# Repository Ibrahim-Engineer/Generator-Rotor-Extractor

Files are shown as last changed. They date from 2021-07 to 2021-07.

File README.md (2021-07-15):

# Generator-Rotor-Extractor

This was a project I was doing for Mechnaic Systems Design, in which we were to implement all the mechanical engineering skills and knowledge we had at our disposal to design a proposal to accomplish something in industry. The following file finaldraft.pdf is the report that should be read to understand the project, while the assembly is going to show the rotor extraction mechanism.

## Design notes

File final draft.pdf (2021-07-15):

## Generator Rotor Extractor

MENG 3309 MSD REPORT

030-Group11

REPORT SUBMITTED BY: Anishkumar Patel

Mohammed Waheed

David Rubio

Luis Rosario

Samuel Thompson

We certify that the narrative, diagrams, figures, tables, calculations and analysis in this report are our own work.

DATE REPORT DUE: | April 25, 2021
DATE REPORT SUBMITTED: | April 25, 2021

MECHANICAL ENGINEERING DEPARTMENT HOUSTON ENGINEERING CENTER COLLEGE OF ENGINEERING
THE UNIVERSITY OF TEXAS AT TYLER

Abstract

Turbine generators are machines that generate electricity by converting mechanical energy

to electrical energy. They are comprised of two main components, a rotor and a stator unit. The

rotor is covered in wires and is spun by mechanical energy inside a stator unit, which has wires

coiled inside, creating an electric magnet. Over time of operation the generator’s components wear

and have to be serviced at a minimum three times a year. This becomes a problem because in order

to access the components to service them the rotor must be extracted from the generator. In this

proposal the rotor model that is tasked to be extracted is from CMT Machines and weights in at

129000 pounds. This proposal is about designing a process in which the rotor will be extracted

using a guided rail system while being pulled by a winch. In order to achieve this, components

were designed to distribute the load of the rotor among two support structures which are further

divided into three components, a seat which supports the rotor, and two Hillman rollers which

support the seat. The next step was to design a guided rail system in which the rollers would

transition the rotor along a two channel rails, both placed on parallel to another. Next the device

that will pull the rotor and supports will be a hydraulic winch model AQ-JM2 by Winch Machines.

Finally, all these components will be held up by a Generator Field Support Platform made by MDA

Turbines. Upon analysis of the components when placing the load of the rotor, the seat was found

to have a safety factor of 15 with a displacement of 7.926E-5 inches. The rollers was then analyzed

where each of the rolls had a safety factor of 15 and a displacement 1.851E-5 inches. The final

analysis for this design was the winch which had a speed of 10.5 inches per second, torque 237741

lbf*in, and 54 Horse Power, when extracting the load of the rotor and its support along the rail

system The one component that can be modified however, in this proposal is the seat due to it

having such a high safety factor it is unnecessary to have a design where too much material is used

to achieve this outcome.

TABLE OF CONTENTS

Introduction

Generators

Turbine generators are devices that convert mechanical energy into electrical energy. The

way this is accomplished is by using an electromagnet, a magnet produced by electricity. The main

components of the generator that produce the electromagnet are the generator stator and the rotor.

The stator unit is a stationary unit with insulated wires coiled around an internal cylinder contained

within the unit. The rotor is comprised of wires coiled and placed on a shaft. The rotor turns within

the stator unit producing the electromagnetic power.

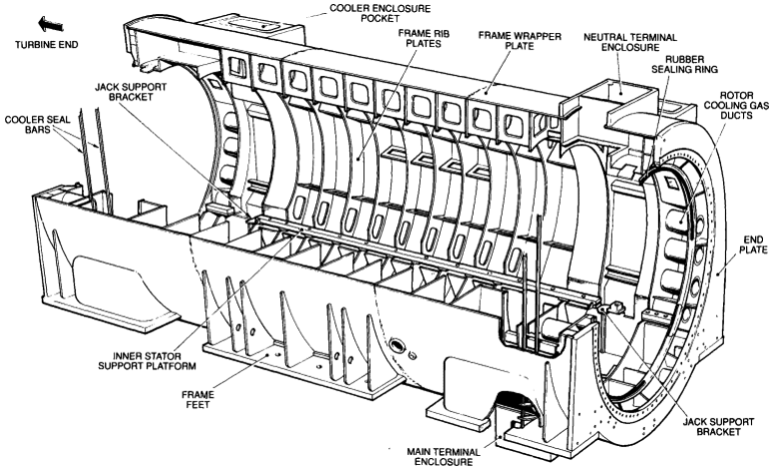
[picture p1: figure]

Fig 1. Depicts a diagram of a generator stator, which houses a rotor [1].

As shown in Fig 1. the stator is what houses the generator rotor, the rotor spins in the stator

and induces a current to produce energy.

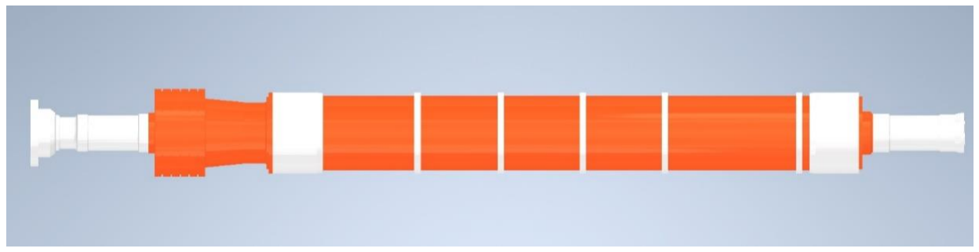
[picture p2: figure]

Fig 2. Generator rotor from City Machines Technology part number 98972-RGXLA [2].

As shown in Fig 2. a rotor shaft is selected and displayed above. This assembly is what

would be housed in the stator when fully operational.

Rotor Maintenance

Overtime the rotor will need some maintenance and may even need to be replaced after the

life cycle of the part comes to an end.

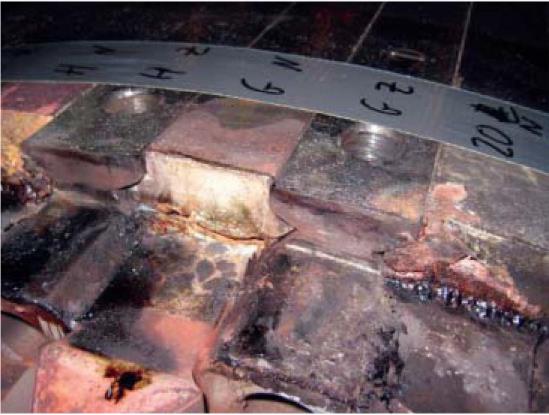
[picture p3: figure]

Fig 3. Image of rotor melted seat with melted insulated coiled wire taken from Figure 2

"Ageing Generator Rotor: Refurbishment or Removal from Service?" [5].

Some of the common damages that can occur to a generator rotor are the coiled wires that

can corroded from wear. As shown in Fig 3., a rotor can experience burns cracks along with its

components and even damage the stator unit inside when in operation. Due to the extensive

components that can wear in a turbine generator, rotors need to be serviced at least three times a year. In order to do this the rotor must be taken out of the stator unit for it to be serviced. This

process is known as generator rotor removal or extraction. Generator rotor extraction is done by a

multi-step process in which multiple mechanisms work in tandem for the rotor to be extracted. The

extraction is done by pulling the rotor from the generator’s stator horizontally while it is suspended

or held up from the bottom in pure translation. If the rotor is not removed in an extremely

controlled fashion, and becomes imbalanced, the rotor can damage the generator stator.

Proposed Method

The motivation of this proposal is to find a way to optimize the process for extracting a

rotor with a minimal cost, a verifiable factor of safety, and a projected life cycle. This can be

achieved by comparing another process for rotor extraction to generator rotor extraction. The

model for the assembly as shown in Fig 2. is what this proposal is challenged with removing from

the stator unit.

In order to remove a rotor from a stator unit a method of extracting has been determined to

be using a rail guided system. The rotor itself will be supported by structures that can support its

weight while being rolled upon a rail. The rotor then will be pulled by a winch using a cable. The

entire structure can then be supported by a platform which will be able to support the forces being

enacted on the structure during the whole process.

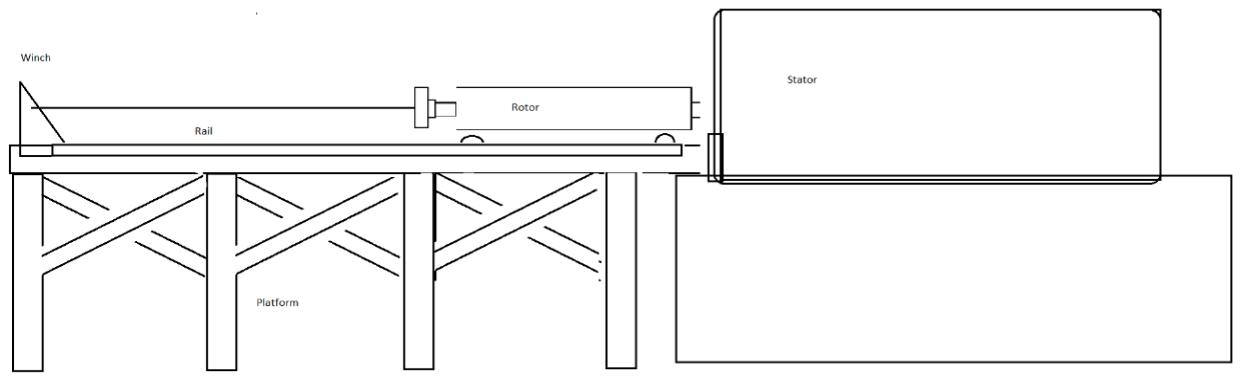
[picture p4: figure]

Fig. 3. Proposed Drawing.

Problem Statement

In designing the proposed design, the ideal process is putting together a detailed design

that will help accomplish the goal of extracting a generator rotor from a stator unit. The following

rotor as shown in Fig 2. from CMT is weighing in at approximately 129000 pounds, is what will

be intended to be extracted for this design. The process in designing an extraction method that is

proposed will present challenges. Such as when finding the distributed weight, the rollers will have

to take from the rotor. Another challenge will be finding a cable winch that can pull the rotor

including its supports. The guided railing system also will have to hold the weight of the rotor and

support system. This rail then has to be placed on a platform that will keep the guided rail in its

intended route, so it won’t be displaced from the shear forces enacting on it by the rotor and the

supports while it is being pulled by the winch.

Objectives

To minimize human error and unintentional damages to a rotor when being extracted; the

process must be optimized with a mechanism to extract the generator rotor. The rotor assembly

must be supported and guided as it is pulled at a safe rate for it to be extracted successfully.

In order to design the rotor extractor a similar method as shown in “Rotor Removal from Large

Machines”, a design of a rotor extractor can be made. The rotor extractor can be split into three

components a guided rail, support structures, and a winch. The guided rail is for the extraction to

occur with precision and not cause the rotor assembly to not damage itself or the stator. The support

structures are to distribute the load of the assembly and move along the guided rail. Finally, the

winch will use a cable that will pull the supports uniformly to ensure they move along the guided

rail. Building on this the goal is to extract the rotor from its stator unit for 55 feet.

Preliminary Literature

In “Rotor Removal from Large Machines”, the process in removing a rotor is shown to be

done by a mechanism that works by pulling a rotor out of its casing while resting on jacks guided

along a determined path [3]. It begins by first pulling the rotor out of the casing slightly till it rests

upon jacks that act as supports. The jacks are aligned to be positioned with the casing of the rotor

so the transition will be smooth. The jacks then will move along the guided tracks for the extraction

to be complete. This method helps show the type of supports that can be designed when moving

the rotor from the stator unit.

In "Predictive Control of Hydraulic Winch Motion Control" hydraulic winches are used to

pull large loads. However, it is stated due to the nonlinear way a load can be pulled when being

dragged by a winch a guided rail system is necessary for the load to be transported in a linear

fashion [4]. This will help with designing a guided rail which will keep the rotor and supports to

be aligned with the winch.

Methodology.

When designing each component, a backwards approach is being taken by first designing

supports which can hold the weight for the rotor and its dimensions. Next, a winch that can pull

the weight of the rotor and the supports can be selected. Finally, the guided rail system with a

platform can be then designed to hold the weight of the rotor, the supports, and a winch at the end.

Supports

The rotor that is most used has dimensions of half a meter in diameter while being 503

inches long and weights roughly 129000 pounds. Based on the dimensions stated a support to carry

this rotor can be designed. The load of the rotor can be distributed between two supports. This

means that the weight for each support will then be the total weight of the rotor and assembly divided by two giving the value 64500 pounds. The location of the supports will be placed along

the assembly for it equal distribution of weight. The supports will be comprising of two

components a seat in which the rotor rests on and two rollers where the seat can roll on.

When designing the seats, it is important to keep in mind where the seats will support the

assembly. The seats must hold an approximate diameter of the rotor has a value of 41 inches.

Another aspect of the seat will be to have two indentation on the bottom for the two rollers.

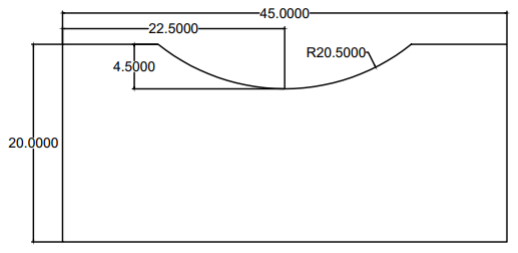
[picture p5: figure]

Fig 4. Shows the sketch of the seat.

As shown in Fig 4., the seat dimensions are made to hold about 41 inches in diameter in

rotor. The seat has been extruded to 18 inches and has slots on the bottom for the rollers. The total

mass for the support is 3332 pounds.

The next component that has to be chosen is the rollers, which will be located on either

side of the seat. The rollers are chosen from Hillman Rollers based on the weight that is being

distributed on each roller. Since the Since the seat adds weight to the distribution along with the

supported weight of the rotor assembly the total weight the rollers have to support is 67832 pounds.

This means each roller will have to support about 33916 pounds. or about 17 us tons. In order for

17 us tons to be supported the Hillman Rollers 20 Ton Capacity T Style Roller 20-T (HIL20-T) is

selected.

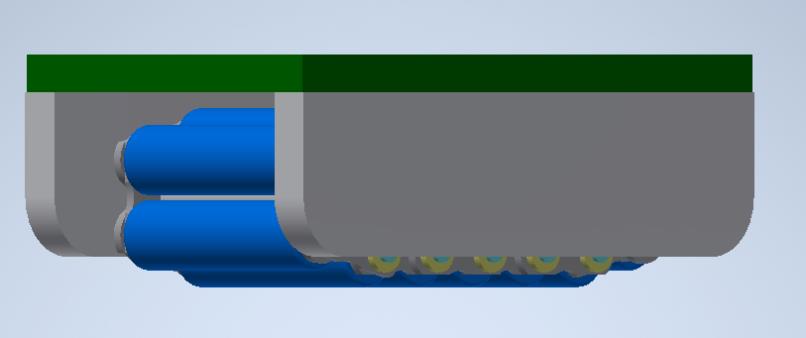
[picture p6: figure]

Fig 5. Shows the HIL20-T Roller which will attach to the seat.

Guided Rail System

After the Seat has been designed and the roller has been selected the next component for

design is the guided rail. The guided rail is for the rollers to roll upon so the rotor assembly will

be moved precisely and safely without being damaged or damaging the stator unit.

The first step is to design a rail with a length that will allow for the rotor to be completely

situated on it when the extraction is complete and for room so personal can service it. Since the

rotor is about 42 feet, a rail system that has the length of 60 feet is being designed. Another aspect

is the channel dimensions of the rail, in which the rollers will move in. According to the Hilman

official dimensions of HIL20-T Roller the width is about 6.5 inches and height is 3.75 inches. Due

to this width the channel width of the rail is 6.5 inches with inner height of the channel 2.5 inches.

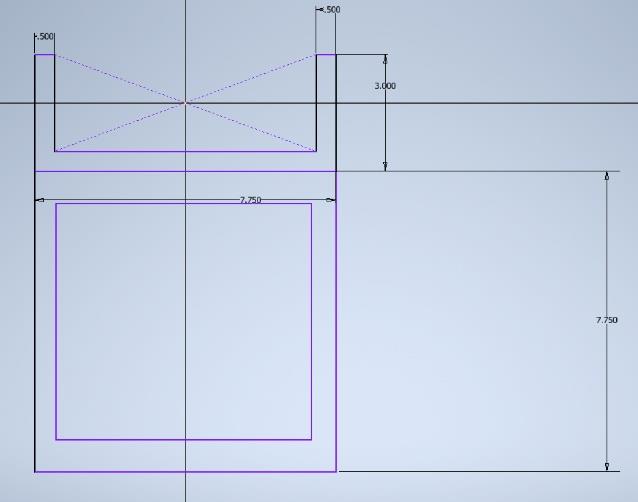
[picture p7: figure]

Fig 6. Shows the sketch of the guided rail component.

The guided rail as seen in Fig 6. has the length of 20 feet. Since the objective is to design

a rail system that will extend to about 60 feet, three components will be used end to end to achieve

the desired length. Also due to the distributed load of the rotor being divided on either side on

rollers, there will be two sets of rails systems put about 20 inches apart. When all put together the

60 feet rail will have 13 sleepers placed 55 inches apart underneath the rail with following

dimensions as shown below

Winch

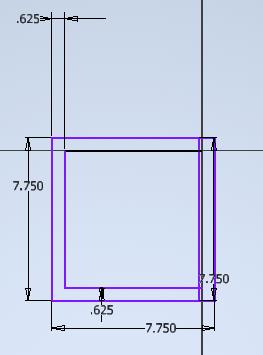
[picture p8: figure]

In order to determine the winch that will be used to extract the rotor the horizontal force

needed to pull the supports and the rotor itself on the guided rail system has to be first determined.

The first step is to find the combined weight of the rotor and supports. There are 4 rollers being

used in total each weighing at 47 pounds., giving a total weight of 188 pounds. There are two seats

being used in the design each weighing at 3355 pounds. giving a total weight of 6670 pounds. All

the support weight combined with the weight of the rotor, 129000 pounds., gives a value of 135870

pounds. Next using the friction coefficient for the steel being used on the rollers, .25, the determined force needed to pull the rotor with the supports come to a value of 33963 pounds or

about 17 U.S. tons.

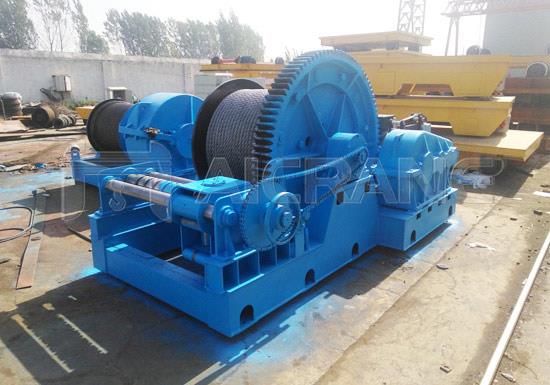
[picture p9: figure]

Fig 7. The AQ-JM2 series hydraulic pull winch.

As shown in Fig 7., the winch, AQ-JM2, has been selected with a pull strength of 20 tons.

Platform

The platform has the length of 65 feet to contain the guided rail system and the winch

which gives a total length of about 63 feet and a width of 5 feet. Based on the dimensions a truss

system along with vertical beams are used to support the structure. These vertical support beams

will be adjusted to level the platform to adhere to the height of the stator unit.

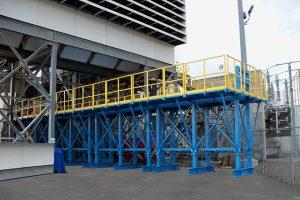
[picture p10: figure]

Fig 8. Shows Generator Field Support Platform from MDA turbines.

As shown in Fig 8. the support platform from MDA Turbines is chosen to be the platform

for this proposal. The platform is able to hold the weight of the rotor, supports, rail guided

system, and winch while still having enough structural integrity to withstand 30 miles per hour

winds when in use. The platform length is 720 inches and is supported by 13 vertical beams

spaced 55 inches apart.

Finally all the components can be assembled in the software inventor to show a simulated

outcome of the proposed design.

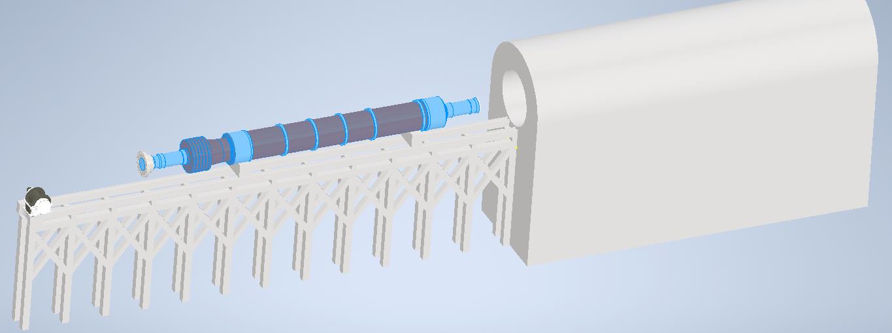
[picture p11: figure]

Fig 9. Shows the assembly of the proposed design on inventor.

Results and Discussion

Now the current design and its assembly is all put together, it is important to look at what

results come from each component, which was specifically designed and not outsourced, when

the load of the rotor is distributed.

The first validation that is needed to confirm whether or not the design can work is the

seat component of the support system. The seat is placed under a force half of the weight of the

rotor. This weight has been calculated to be about 64500 pounds. Using the inventors stress

analysis tool, one can determine the safety factor, displacement due to deformation, and mass of

the material being used of the component.

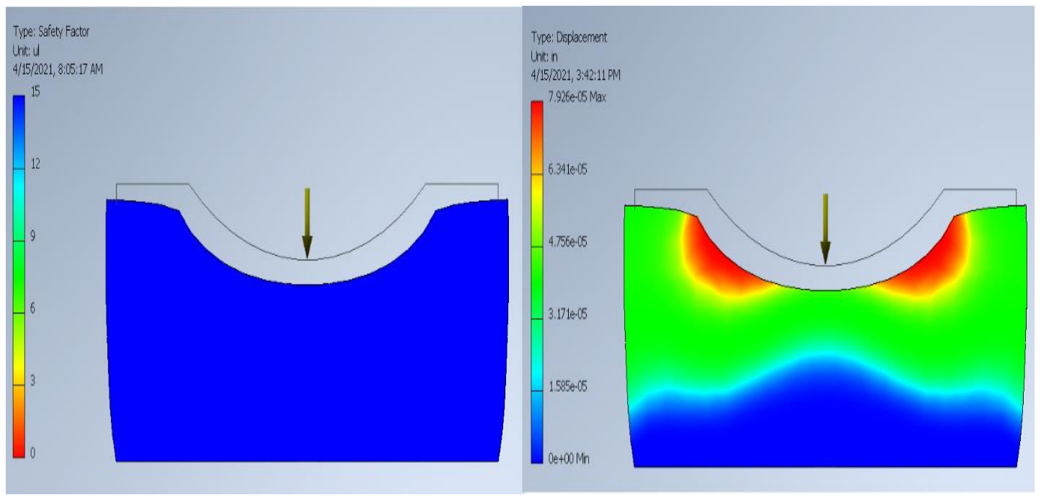
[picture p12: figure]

Fig. 10 Safety factor and Displacement due to deformation for the seat component.

From Fig. 10 one can see the stress analysis that the seat went through. The displacement

value was found to be 7.926E-5 inches when a load of 64500 pounds was placed on the seat. The

safety factor was found to be 15 ul. From this analysis it can shown that seats component will be

able to hold the distributed weight of the rotor.

The next component that can be analyzed is then rail system which can be determined

based on the distributed load of the hillman roller, two of which will be situated under each seat.

Each roller will have the distributed weight of half of the rotor and half of the seat, which is a

load of 33916 pounds. The roller when in use has 5 rolls in contact with the surface of the rail

allowing the load of 33916 pounds to be distributed among the 5 rolls. Each roll will therefore

have to support the weight of 6783.2 pounds. Based on the dimensions of the roll as shown from

the Hillman website, the diameter of the roll is 1.1875 inches and the length of the roll is 4

inches [8]. Each roll is made of high steel.

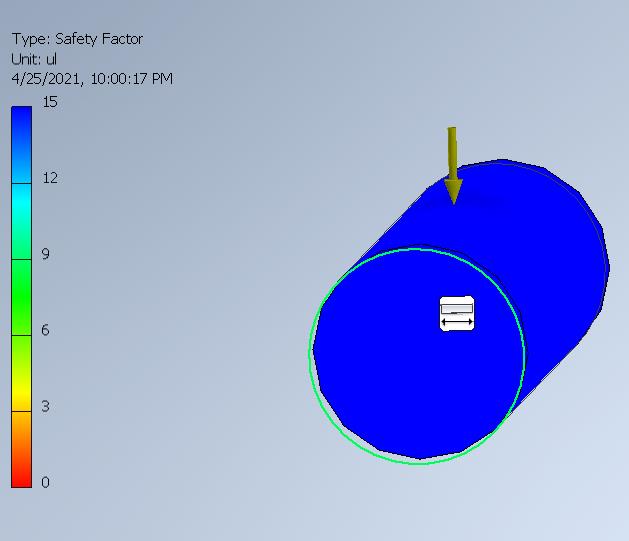
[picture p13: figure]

Fig. 11 Safety factor and Displacement due to deformation for the roll for roller component.

After using inventor stress analysis on the roll of the roller with 6873.2 pounds of force

being placed on it, a safety factor of 15 was found while the displacement was 1.851E-5 inches.

These values obtained from the analysis help determine that the HIL20-T Roller is able to

support the distributed load while still functioning in the transition of the load.

The next analysis done is on the winch. The winch model is the AQ-JM2, the analysis of

this component covers the speed and torque of the drum that pulls the cable with load of the rotor

and supports system when moving along the rail system. The winch is rated to have a speed of

16 meters per minute which is 10.5 inches per second. Next based on the load that is pulled by

the winch and the drum diameter to calculate torque. The drum is estimated to have diameter of

.35 meters which is about 14 inches in diameter. The amount of force that is being pulled has

already been calculated in the previous section to be 33963 pounds. When calculating torque the

drum diameter which is 7 inches multiplied by 33963 pounds give a value of 237741 lb*in of torque. In order to find the amount of power that is being used in the process of extracting the

rotor the following formula has to be used. As shown below

Power(HP) =

Torque∗speed(RPM)
63,025

(1)

The speed for RPM can be found from the velocity at which the rotor will be extracted,

10.5 inches per second and diameter of the drum of the winch, 14 inches. This gives a value of

14.32 RPM. Using the previously stated formula above the power in horsepower is calculated to

be about 54 horsepower when extracting the rotor from the stator unit.

Conclusion

In conclusion, the proposed design of a generator rotor extractor is successful based on

the analysis done on each component that makes up the design. This is confirmed by the

calculated and given information of each component’s safety factor when placed under the load

of the rotor, by CMT Machines, that is being extracted. The design makes sure to allow for the

rotor to be supported by a seat and rollers which are to be extracted while being guided on a rail

system and be pulled by a hydraulic winch, while the entire process is held by a generator

support platform.

However, the analysis also showed how material was wasted for the seat structure that

held the rotor. This is due to it having a large safety factor of 15 ul, which is shows that the same

condition of the rotor being supported sufficiently can be achieved by scaling down the material

being used for the design.

Another aspect of the design that can be modified for another environmental use is the

rail system. Since the proposed design is meant for a particular extraction of a rotor from stator

unit that is outside the rail system that was used was designed to be placed on a platform.

However, if the design were to be modified where instead of a channel rail, a flat rail were used, the extraction can be used on ground level where the rail system was bolted to concrete. This is a

method where a stator unit that is located indoors on ground level would be used

References

[1] British Electricity International, in Turbines, Generators and Associated Plant (Third

Edition), 1991

[2] "Products in the News: Enerpac Wins Contract to Build a Rotor Removal System for S.T.

Cotter Turbine Services." Products in the News: Enerpac Wins Contract to Build a Rotor

Removal System for S.T. Cotter Turbine Services. Newstex, 2016. Web.

[3] "Rotor Removal from Large Machines." Electrical Engineering 66.12 (1947): 1214-215.

Web.

[4] Zhou Entao, Yang Wenlin, and Lin Junzhe. "Predictive Control of Hydraulic Winch

Motion Control." 2009 2nd IEEE International Conference on Computer Science and

Information Technology (2009): 1-4. Web.

[5] Ebi, Günter. "Ageing Generator Rotor: Refurbishment or Removal from Service?" Power

Engineering International 17.5 (2009): 118-23. Web.

[6] | Shibin | Wang, Xuefeng Chen, Guoying Li, | Xiang | Li, | & Zhengjia He. | (2014).

Matching Demodulation Transform With Application to Feature Extraction of Rotor Rub-

Impact Fault. IEEE Transactions on Instrumentation and Measurement, 63(5), 1372-

| 1383.
[7] “American Standard Steel C Channels,” Engineering ToolBox, 2008. [Online]. Available:

https://www.engineeringtoolbox.com/american-standard-steel-channels-d_1321.html.

[8] https://www.ohiopowertool.com/p-13426-hilman-rollers-20-ton-capacity-t-style-roller-
| 20-t.aspx

Appendix

Appendix A

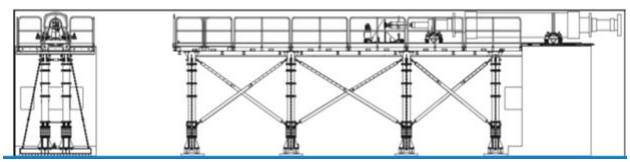
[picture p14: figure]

Fig 1. Shows the “Rotor Removal from Large Machines." diagram.

Appendix B

Writing Center Availability.

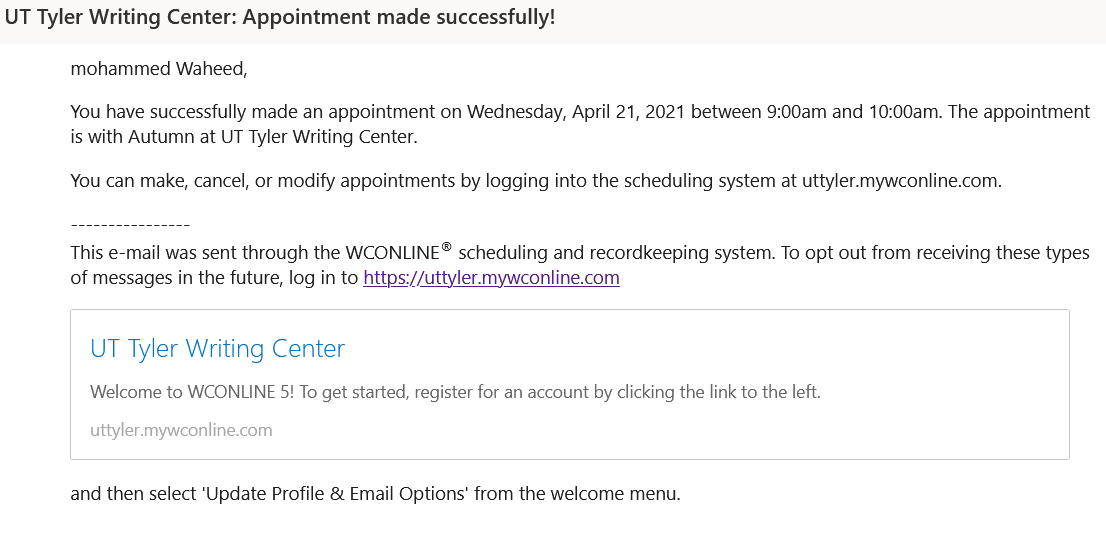
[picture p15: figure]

Appendix C

Work Hours of Participation

scaffolding 1
| 25-Feb | 26-Feb | 27-Feb | 28-Feb | 1-Mar | 2-Mar | 3-Mar | 4-Mar
Anishkumar Patel | 9:30 P.M.-10:30 P.M. 9:30 P.M.-10:30 P.M. | 9:30 P.M.-10:30 P.M. 9:30 P.M.-10:30 P.M. | 9:30 P.M.-10:30 P.M. 9:30 P.M.-10:30 P.M. | 9:30 P.M.-10:30 P.M. 9:30 P.M.-10:30 P.M. | 9:30 P.M.-10:30 P.M. 9:30 P.M.-10:30 P.M. | 9:30 P.M.-10:30 P.M. 9:30 P.M.-10:30 P.M. | 9:30 P.M.-10:30 P.M. 9:30 P.M.-10:30 P.M. | 9:30 P.M.-10:30 P.M. Mohammed Waheed 9:30 P.M.-10:30 P.M.
David Rubio | 9:30 P.M.-10:30 P.M. | 9:30 P.M.-10:30 P.M. | 9:30 P.M.-10:30 P.M. | 9:30 P.M.-10:30 P.M. | 9:30 P.M.-10:30 P.M. | 9:30 P.M.-10:30 P.M. | 9:30 P.M.-10:30 P.M. | 9:30 P.M.-10:30 P.M.
Luis Rosario | 9:30 P.M.-10:30 P.M. | 9:30 P.M.-10:30 P.M. | 9:30 P.M.-10:30 P.M. | 9:30 P.M.-10:30 P.M. | 9:30 P.M.-10:30 P.M. | 9:30 P.M.-10:30 P.M. | 9:30 P.M.-10:30 P.M. | 9:30 P.M.-10:30 P.M.
Samuel Thompson | 9:30 P.M.-10:30 P.M. | 9:30 P.M.-10:30 P.M. | 9:30 P.M.-10:30 P.M. | 9:30 P.M.-10:30 P.M. | 9:30 P.M.-10:30 P.M. | 9:30 P.M.-10:30 P.M. | 9:30 P.M.-10:30 P.M. | 9:30 P.M.-10:30 P.M.

scaffolding 2
| 25-Mar | 26-Mar | 27-Mar | 28-Mar | 29-Mar | 30-Mar | 31-Mar | 1-Apr
Anishkumar Patel | 9:30 P.M.-10:30 P.M. 9:30 P.M.-10:30 P.M. | 9:30 P.M.-10:30 P.M. 9:30 P.M.-10:30 P.M. | 9:30 P.M.-10:30 P.M. 9:30 P.M.-10:30 P.M. | 9:30 P.M.-10:30 P.M. 9:30 P.M.-10:30 P.M. | 9:30 P.M.-10:30 P.M. 9:30 P.M.-10:30 P.M. | 9:30 P.M.-10:30 P.M. 9:30 P.M.-10:30 P.M. | 9:30 P.M.-10:30 P.M. 9:30 P.M.-10:30 P.M. | 9:30 P.M.-10:30 P.M. Mohammed Waheed 9:30 P.M.-10:30 P.M.
David Rubio | 9:30 P.M.-10:30 P.M. | 9:30 P.M.-10:30 P.M. | 9:30 P.M.-10:30 P.M. | 9:30 P.M.-10:30 P.M. | 9:30 P.M.-10:30 P.M. | 9:30 P.M.-10:30 P.M. | 9:30 P.M.-10:30 P.M. | 9:30 P.M.-10:30 P.M.
Luis Rosario | 9:30 P.M.-10:30 P.M. | 9:30 P.M.-10:30 P.M. | 9:30 P.M.-10:30 P.M. | 9:30 P.M.-10:30 P.M. | 9:30 P.M.-10:30 P.M. | 9:30 P.M.-10:30 P.M. | 9:30 P.M.-10:30 P.M. | 9:30 P.M.-10:30 P.M.
Samuel Thompson | 9:30 P.M.-10:30 P.M. | 9:30 P.M.-10:30 P.M. | 9:30 P.M.-10:30 P.M. | 9:30 P.M.-10:30 P.M. | 9:30 P.M.-10:30 P.M. | 9:30 P.M.-10:30 P.M. | 9:30 P.M.-10:30 P.M. | 9:30 P.M.-10:30 P.M.

scaffolding 3
| 7-Apr | 8-Apr | 9-Apr | 10-Apr | 11-Apr | 12-Apr | 13-Apr | 14-Apr | 15-Apr
Anishkumar Patel | 9:30 P.M.-10:30 P.M. 9:30 P.M.-10:30 P.M. | 9:30 P.M.-10:30 P.M. 9:30 P.M.-10:30 P.M. | 9:30 P.M.-10:30 P.M. 9:30 P.M.-10:30 P.M. | 9:30 P.M.-10:30 P.M. 9:30 P.M.-10:30 P.M. | 9:30 P.M.-10:30 P.M. 9:30 P.M.-10:30 P.M. | 9:30 P.M.-10:30 P.M. 9:30 P.M.-10:30 P.M. | 9:30 P.M.-10:30 P.M. 9:30 P.M.-10:30 P.M. | 9:30 P.M.-10:30 P.M. 9:30 P.M.-10:30 P.M. | 9:30 P.M.-10:30 P.M. Mohammed Waheed 9:30 P.M.-10:30 P.M.
David Rubio | 9:30 P.M.-10:30 P.M. | 9:30 P.M.-10:30 P.M. | 9:30 P.M.-10:30 P.M. | 9:30 P.M.-10:30 P.M. | 9:30 P.M.-10:30 P.M. | 9:30 P.M.-10:30 P.M. | 9:30 P.M.-10:30 P.M. | 9:30 P.M.-10:30 P.M. | 9:30 P.M.-10:30 P.M.
Luis Rosario | 9:30 P.M.-10:30 P.M. | 9:30 P.M.-10:30 P.M. | 9:30 P.M.-10:30 P.M. | 9:30 P.M.-10:30 P.M. | 9:30 P.M.-10:30 P.M. | 9:30 P.M.-10:30 P.M. | 9:30 P.M.-10:30 P.M. | 9:30 P.M.-10:30 P.M. | 9:30 P.M.-10:30 P.M.
Samuel Thompson | 9:30 P.M.-10:30 P.M. | 9:30 P.M.-10:30 P.M. | 9:30 P.M.-10:30 P.M. | 9:30 P.M.-10:30 P.M. | 9:30 P.M.-10:30 P.M. | 9:30 P.M.-10:30 P.M. | 9:30 P.M.-10:30 P.M. | 9:30 P.M.-10:30 P.M. | 9:30 P.M.-10:30 P.M.

Final Draft
| 23-Apr | 24-Apr | 25-Apr
Anishkumar Patel | 9:30 P.M.-10:30 P.M. 9:30 P.M.-10:30 P.M. | 9:30 P.M.-10:30 P.M. 9:30 P.M.-10:30 P.M. | 9:30 P.M.-10:30 P.M. Mohammed Waheed 9:30 P.M.-10:30 P.M.
David Rubio | 9:30 P.M.-10:30 P.M. | 9:30 P.M.-10:30 P.M. | 9:30 P.M.-10:30 P.M.
Luis Rosario | 9:30 P.M.-10:30 P.M. | 9:30 P.M.-10:30 P.M. | 9:30 P.M.-10:30 P.M.
Samuel Thom+B3:J36pson9:30 P.M.-10:30 P.M. | | 9:30 P.M.-10:30 P.M. | 9:30 P.M.-10:30 P.M.

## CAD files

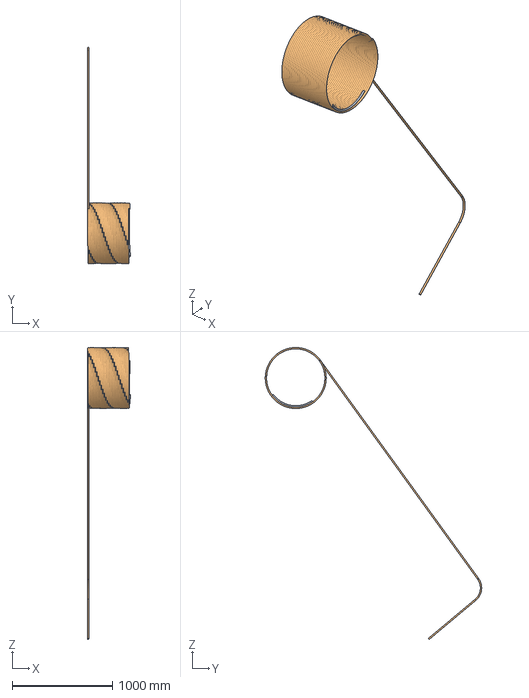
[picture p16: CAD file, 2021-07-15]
little winch cable.stp
431.0 x 2162.5 x 2915.7 mm

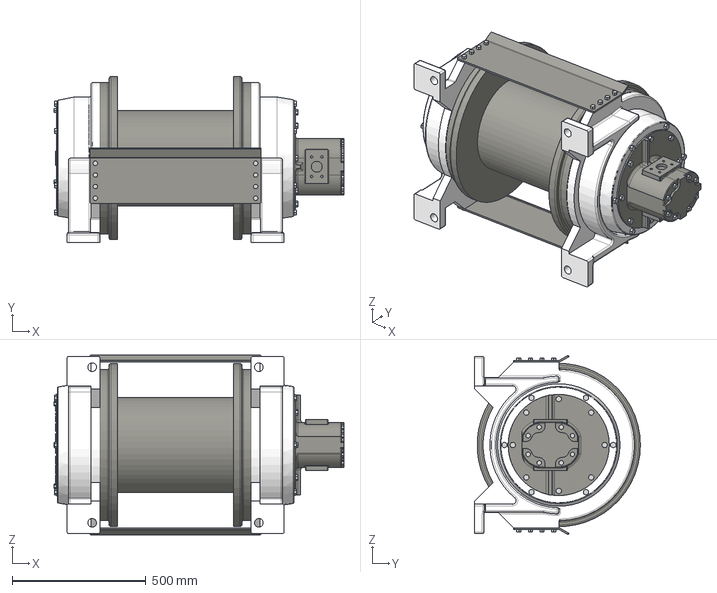
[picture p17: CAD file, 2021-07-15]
GH30B.stp
1082.7 x 619.1 x 670.6 mm

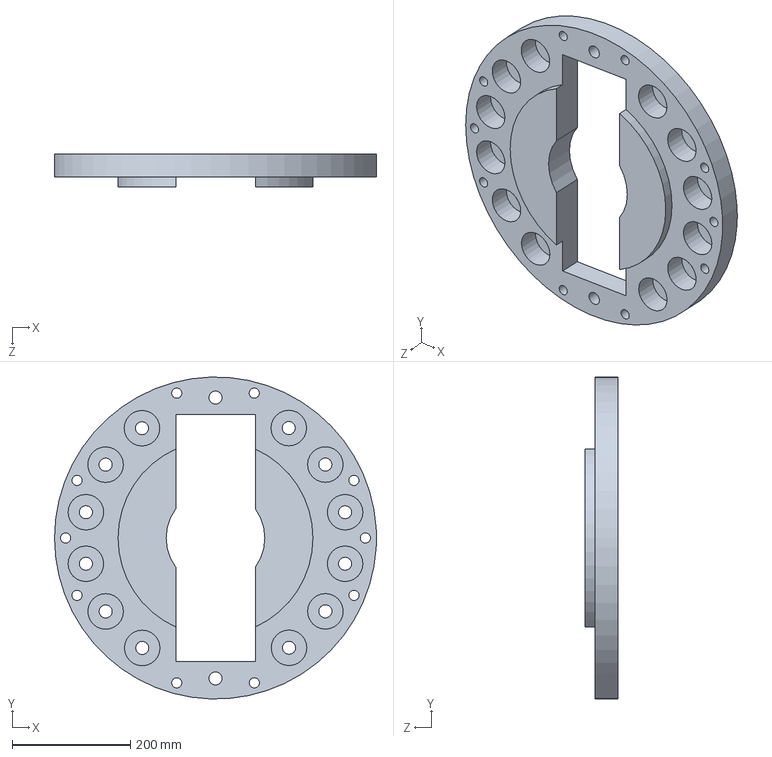
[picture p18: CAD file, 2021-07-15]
City Machine Technologies-98972-RGALA_98972-CGELA.SLDPRT
545.6 x 545.3 x 56.7 mm

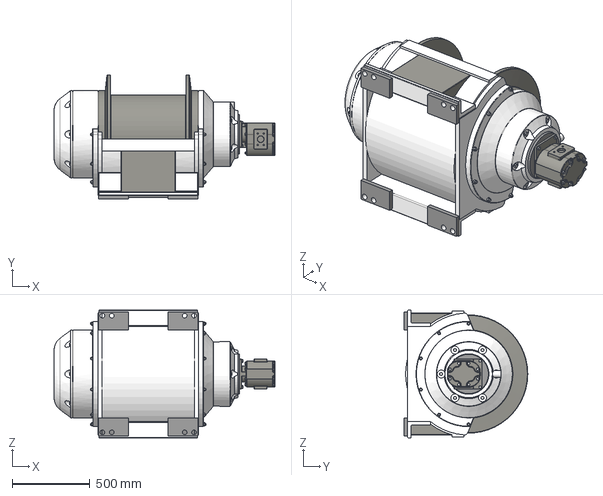
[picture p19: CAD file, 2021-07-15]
GH50 winch.stp
1424.6 x 796.9 x 822.3 mm

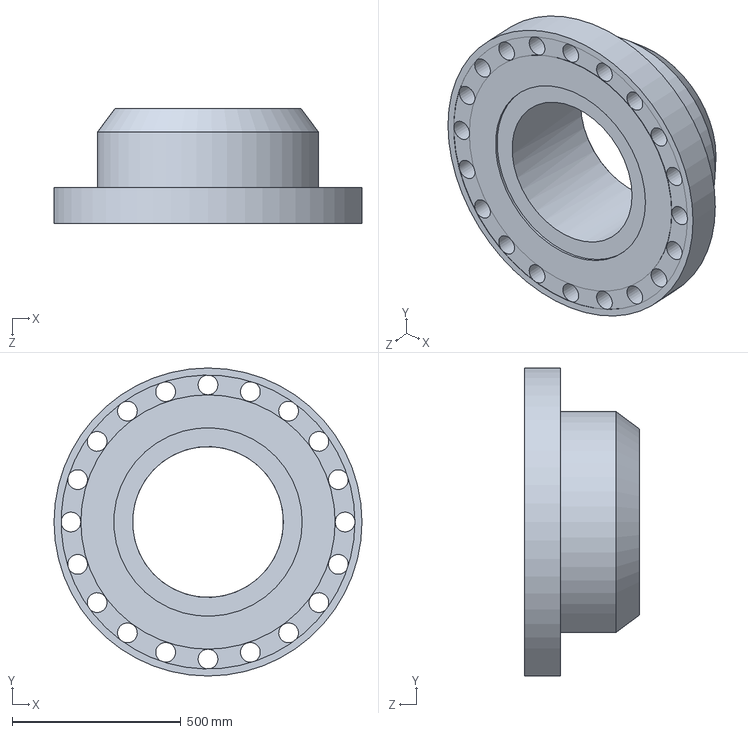
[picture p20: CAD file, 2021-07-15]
City Machine Technologies-98972-RGALA_98972-CGTLA.SLDPRT
913.2 x 913.2 x 341.3 mm

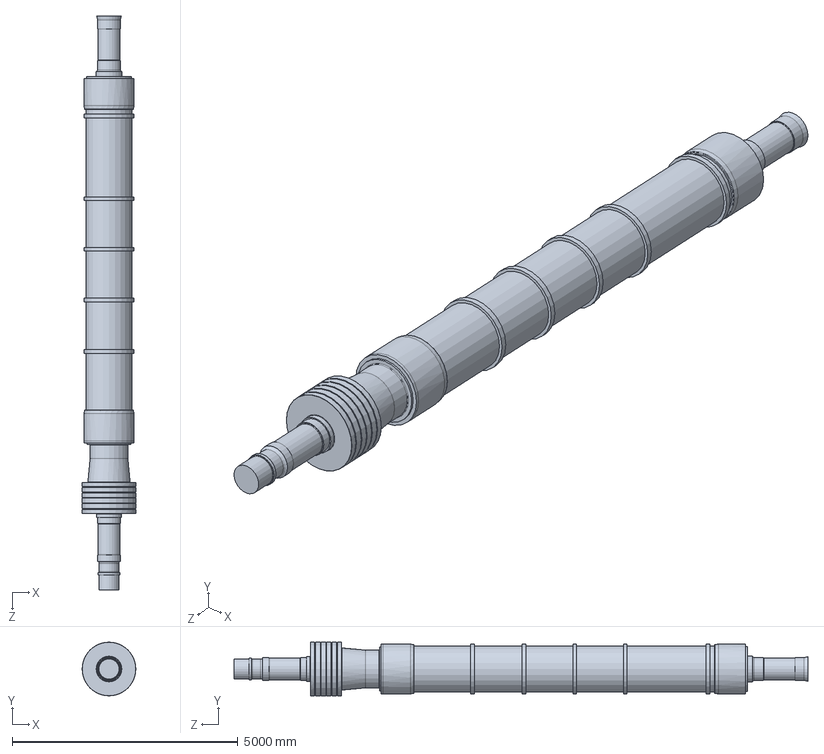
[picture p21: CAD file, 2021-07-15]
City Machine Technologies-98972-RGALA_98972-RGXLA.SLDPRT
1190.6 x 1190.6 x 12704.5 mm

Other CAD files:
City Machine Technologies-98972-RGALA.DWG
Assembly1.iam
City Machine Technologies-98972-RGALA_98972-CGELA.ipt
City Machine Technologies-98972-RGALA_98972-CGTLA.ipt
City Machine Technologies-98972-RGALA_98972-RGXLA.ipt
GH50 winch.ipt
platform part.ipt
rail part.ipt
rail.ipt
roller placemnet.ipt
seat.ipt
stator unit.ipt
